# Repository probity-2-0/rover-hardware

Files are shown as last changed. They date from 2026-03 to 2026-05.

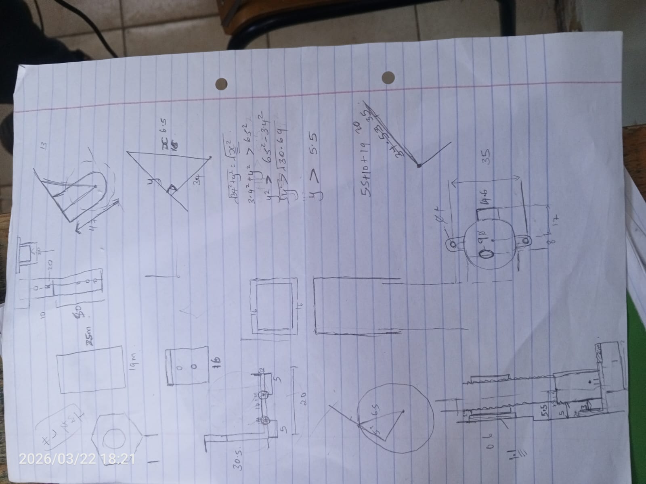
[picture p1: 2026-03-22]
images/SUSPENSION.jpeg

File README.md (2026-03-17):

# # Rover Hardware
Hardware design(Mechaical & Electrical design files) and documentation for the rover, including schematics, wiring diagrams, components, embedded system interfaces, CAD models(fusion 360).

This repository contains all mechanical and electrical designs for the Mars Rover project.

## Contents
- Mechanical design (CAD, chassis, structure)
- Electrical systems (schematics, wiring, PCB)
- Components and parts list (BOM)
- Hardware images and prototypes

## Structure
- mechanical/
- electrical/
- components/
- images/

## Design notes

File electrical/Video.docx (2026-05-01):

This documentation guide addresses the technical integration of a RunCam FPV Camera with a Network Card (WiFi Dongle) for digital FPV transmission and RunCam WifiLink, likely via the OpenIPC or RubyFPV ecosystem.

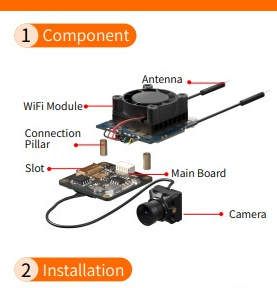
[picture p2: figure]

1. Video Signal Interface (Digital)

In this specific setup, the "Interface" is actually a two-part bridge:

- Camera to Main Board
- Main Board to WiFi Dongle

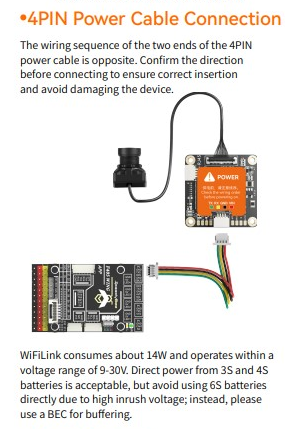
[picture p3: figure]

Operating Voltage & Current Draw

Digital transmission requires high current stability. Voltage ripple should be kept below 100mV.

- Operating Voltage: 9V – 30V (Optimized for 3S/4S LiPo).
- Typical Current (Idle): 450mA @ 12V.
- Typical Current (Streaming): 1.2A @ 12V.
- Max Peak Current: 2.5A @ 12V (During high-bitrate scene changes or extreme range transmission).

2. WiFi Channel & Frequency Configuration

The system uses the 5.8 GHz band. It is highly configurable via a text file on the SD card.

- Default Frequency: 5.8 GHz.
- Supported Power: Up to 29dBm (approx. 800mW) on FCC settings.
- Channel Selection: Recommended to use Channel 149 (5745 MHz) to 165 (5825 MHz) to stay clear of standard WiFi routers.
- Codec: H.265 is preferred for digital FPV as it offers better quality at lower bitrates, reducing latency.
- Ground Station: ground station WiFi dongle must be put into Monitor Mode.Need the gs.key file (automatically generated on the camera's SD card) to decrypt the video stream on your ground station device.

3. Antenna Placement (LoRa Interference Check)

Since the rover also carries a LoRa link:

- WiFi Antenna: 5.8 GHz (Circular Polarized or "Mushroom" antennas are best for multi-path rejection).
- LoRa Antenna: 433/868/915 MHz (Linear Monopole/Dipole).
- Interference Rule: WiFi 5.8 GHz is a harmonic of some lower frequencies. Keep the WiFi antenna at least 20cm away from the LoRa antenna. If you experience "telemetry lost" when the video starts, the WiFi dongle is likely "swamping" the LoRa receiver.

4.Specification

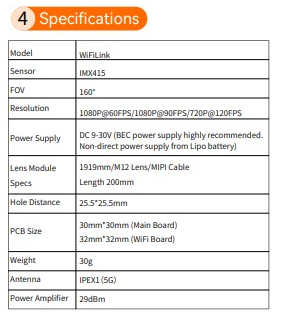
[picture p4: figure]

5. Mounting Strategy (Remote Cable-Mount)

The WiFiLink 2 is modular. You can "remote-mount" components to balance the rover or move the RF source.

- Camera Mount: The sensor (19x19mm) can be mounted up to 130mm away from the main board using the provided MIPI cable.
- Board Mount: The main PCB (32x 32mm) should be mounted on 25.5mm stacks.
- Thermal Note: The board must have its cooling fan active. If the green/blue lights flash alternately, the board has exceeded 90°C and will throttle or shut down.
- WiFi Dongle: Can be remote-mounted using a 4-wire shielded cable to place the antenna in the most optimal RF location.

6.Ground Station Configuration

To receive the signal on the ground station side, you need:

1. Hardware: A high-power WiFi dongle (typically RTL8812AU or MT7612U chipsets).
2. Software:
  - Android: FPVue or PixelPilot.
  - PC: Use the FPV4Win tool.

GS Key Management: Always keep a backup of the gs.key on a secondary device. If you lose this file from the SD card, you will lose the ability to decrypt the video stream on your Ground Station.

7.Communication Protocol

- Internal (Cam to Board): MIPI CSI-2 (4-Lane).
- External (Board to GS): UDP/RTSP over WiFi (Monitor Mode).
- Telemetry: MAVLink via UART (compatible with ArduPilot/PX4).
- Control: I2C is used internally for sensor configuration; it is not exposed for user control.

6. Testing Procedure (Bench Test Checklist)

1. Continuity Check: Verify no shorts between VCC and GND before applying power.
2. Voltage Check: Confirm the BEC/PDB outputs 12V stable under load.
3. LED Status: Red Solid (Power), Blue Flashing (System Boot), Green Solid (WiFi Link Active).
4. Ping Test: Connect GS to WiFi and ping the camera IP (Default: 192.168.1.10).
5. Latency Check: Measure glass-to-glass latency (Target < 80ms

8. Board Placement & Thermal Rules

- Thermal: The SoC generates significant heat. The board must be mounted with at least 5mm of clearance underneath for airflow.
- Proximity: Keep the WiFiLink board at least 50mm away from the GPS module and 150mm away from the LoRa receiver.
- Mounting: Use M2 nylon standoffs to prevent shorting against carbon fiber or metal rover frames.

PCB Trace Width Recommendations

For the JST_GH_1x04_P1.25mm connector, the power traces must be sized to handle peak current without significant voltage drop or heat buildup.

- VCC & GND Traces: Use a trace width of at least 1.0 mm (40 mils) for internal or external layers if using standard 1oz copper. This safely handles the 2.5A peak current while keeping temperature rise under 10°C.
- UART Data Traces (TX/RX): These carry minimal current and can be thin, typically 0.2 mm (8 mils), but keep them away from high-power traces to avoid EMI.
- Polygon Pours: Whenever possible, use a Ground Plane on the layer directly beneath the WiFiLink to provide a short return path for high-frequency noise.

79 Firmware & Code Notes

- OS: Linux-based OpenIPC.
- Library: Uses WFB-ng (WiFi Broadcast next generation) for the transmission layer.
- HAL: The hardware abstraction layer is proprietary to the SigmaStar SoC, but can be modified via /etc/config/ files via SSH.
- Root Access: ssh root@192.168.1.10 (Default password is often 12345 or runcam).

10. Recommended Schematic Circuit

When integrating this into your rover's power distribution board (PDB):

- Decoupling: Place a 470µF 35V Low-ESR Capacitor across the DC input to filter motor noise.
- Protection: Add a TVS Diode (e.g., SMBJ24A) to protect against voltage spikes from the rover's motors.
- Symbol Name: JST_GH_1x04_P1.25mm

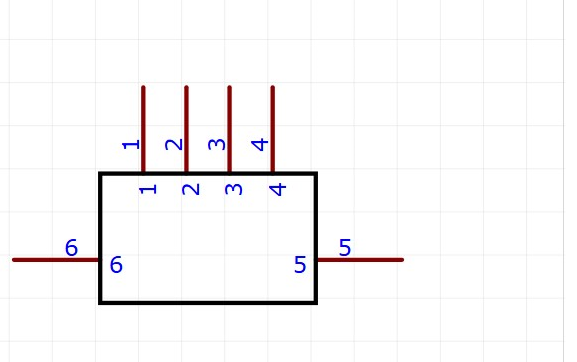
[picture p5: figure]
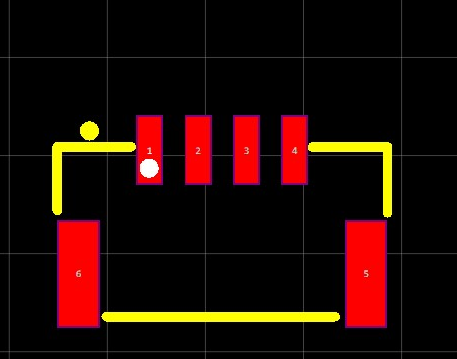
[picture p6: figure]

General Description and Purpose

The JST_GH_1x04 is a 4-pin, 1.25mm pitch wire-to-board connector symbol used to define the primary electrical interface for the WiFiLink system. In professional electronics design, this symbol serves three critical purposes for your rover build:

- Power Delivery Integration: It provides the schematic connection point for the 9V–30V DC input, ensuring the high-current requirements (up to 2.5A peak) are routed through traces capable of handling the load.
- Telemetry Communication Bridge: The symbol maps the UART TX and RX lines, allowing you to establish a MAVLink communication protocol between the WiFiLink board and the rover's flight controller or main processor

Pin | Function | Description
1 | VCC | Main Power Input
2 | GND | Common System Ground
3 | TX | Data output to Flight Controller (Telemetry)
4 | RX | Data input from Flight Controller (Control)
5 & 6 | Shielding | which should be soldered to a grounded plane for physical stability and additional noise shielding

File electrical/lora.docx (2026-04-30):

E220-400T22D adopts a new generation of LoRa spread spectrum technology and a wireless serial port module (UART) designed based on the LLCC68 chip scheme. It has a variety of transmission methods, works in the (410.125～493.125MHz) frequency band (default 433.125MHz), TTL level output, compatible with 3.3V and 5V IO port voltage.

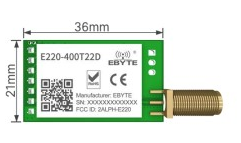
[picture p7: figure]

Pinout Description

The module generally includes the following pins, starting from the antenna end:

Pin Name | Description
M0 | Mode selection pin 0 (Used with M1 for sleep/wake/power-saving modes)
M1 | Mode selection pin 1 (Used with M0)
RXD | TTL UART Serial Input (Connects to MCU TX)
TXD | TTL UART Serial Output (Connects to MCU RX)
AUX | Auxiliary indication (Indicates module state, wakes up external MCU)
VCC | Power Supply (Typically 3.3V - 5.2V)
GND | Ground (0V)

Key Features

- Operating Frequency: 433-532MHz band
- Interface: UART (Serial)
- Distance: Long-range (LoRa technology)
- Antenna: SMA or solder pin for external antenna (essential for range)
- Operating Temperature: -40~+85 ℃

Performance:

- Output Power: +22dBm
- Maximum Receiving Sensitivity: -135dBm (BW=125, SF=12)
- Open space visible distance up to 8km (for reference only, actual distance may vary)

EASYEDA SCHEMATIC/DIAGRAM

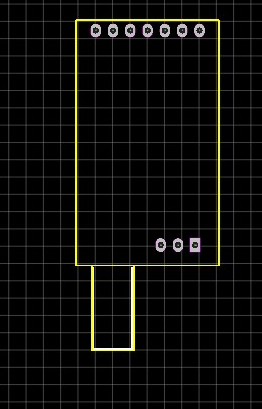
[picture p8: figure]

FootPrint

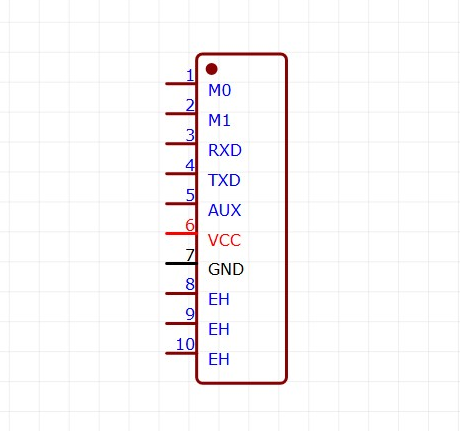
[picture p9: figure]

Hardware Design Layout Suggestions

The E220-400T22D module operates in the 433-532M frequency band and uses an external antenna. The antenna's VSWR and efficiency depend on the module's placement. Minimize factors affecting wireless transmit and receive signals. Pay attention to the following points:

Avoid using metal for the product casing surrounding the E220-400T22D. If using a partial metal casing, keep the module's antenna section as far away from the metal as possible. Internal metal connections or screws should also be kept away from the module's antenna section.

The module's antenna section should be placed near the edge of the carrier board PCB or directly exposed, and should not be placed in the middle of the board.

It is recommended to use insulating material for isolation at the module mounting position on the baseboard, such as a complete silk screen (TopOverLay) at this location

Recommended Circuit

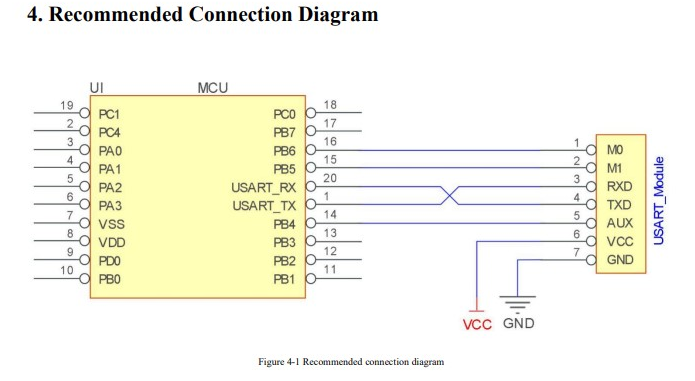
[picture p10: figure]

Precautions

- Power Check: Ensure the module is receiving stable power within the specified voltage range (3.3V-5.5V).
- Antenna Connection: Verify that the antenna is securely connected before powering on the module. An unconnected antenna can lead to damage.
- UART Connection: Double-check your RXD and TXD connections to your microcontroller or computer. Ensure baud rates match.
- AT Command Syntax: Confirm that the AT commands sent are correctly formatted and terminated. Refer to the technical manual for exact syntax.
- Frequency Band: Ensure both transmitting and receiving modules are configured to the same frequency band.
- Communication Range: Consider environmental factors (obstacles, interference) that might affect the actual communication range. The stated 8km range is for open, unobstructed environments.
- Module Operating Mode: Verify that the M0 and M1 pins are configured correctly for the desired operating mode (e.g., transparent, fixed-point).

TX power setting and link budget calculation

TX Power Settings

The maximum transmit power for these "22D" series modules is typically +22 dBm (160mW).

- Adjustment Range: Usually configurable from 0 dBm to +22 dBm in steps.
- Power Consumption: Higher TX power significantly increases current draw during transmission. For example, at +22 dBm, the module may draw over 100mA, whereas lower settings like +10 dBm draw much less.
- Regulatory Limits: In many regions, the 433 MHz ISM band has strict effective radiated power (ERP) limits (often 10mW or 14 dBm) and duty cycle restrictions. Ensure your settings comply with local laws

Link Budget Calculation

The link budget is the sum of all gains and losses in your communication system. It determines the maximum path loss your signal can survive before it becomes unreadable

Received Power(dBm)=PTX+GTX-LTX-FSPL+GRX-LRX

PTX(TX Power): Your setting (e.g., +22 dBm).

GTX/GRX(Antenna Gain): Typical rubber ducky antennas are ~2 dBi.

LTX/LRX(Cable/Connector Loss): Usually ~0.5–1 dB for direct SMA connections.

FSPL (Free Space Path Loss): The loss over distance d (km) at frequency (MHz):

FSPL=20log10(d) + 20log10(f)+32.45

Fade Margin: Always subtract a safety margin (e.g., 10–15 dB) for obstacles and weather to ensure reliability.

Range Test Protocol

Step 1: Static Bench Test (0.5km)

- Goal: Verify the ACK Loop logic works.
- Action: Send 100 commands. If the Ground Station logs 100 ACKs, the firmware is stable.

Step 2: Line-of-Sight (LoS) Test (5km - 8km)

- Action: Have the Rover assignee move to a clear hilltop.
- Data: Record the RSSI (Signal Strength) and SNR (Signal Quality) reported by the module.
- Orientation: Test if holding the Ground Station antenna Vertical vs. Horizontal changes the signal.

Step 3: Failure Boundary Test

- Action: Move until the "Heartbeat" starts dropping.
- Goal: Confirm the Rover's Fail-Safe triggers (Motors stop) when the signal is lost.

Firmware and Code Libraries

The E220-400T22D is primarily a UART-based module, meaning most developers interact with it via serial strings rather than low-level register manipulation

1. Core Architecture

- Driver Type: Because the module includes an onboard MCU to handle the LoRa stack, you generally use HAL drivers for UART on your host controller (e.g., STM32 HAL, Arduino Serial) rather than SPI HAL drivers for the LoRa chip itself.

2. Register Maps & Configuration

The module does not expose the raw SX1262 register map over UART. Instead, it uses a Virtual Register Map accessed via AT commands.

- Configuration Storage: Settings changed via AT commands are typically stored in the LLCC68's internal Flash/EEPROM, persisting through power cycles.
- Register Access: This specific EByte module usually uses Hexadecimal Configuration Commands

3. Recommended Libraries

For most microcontrollers, you do not need a specific "LR32" library. You can use standard serial libraries:

- Arduino: SoftwareSerial (https://docs.arduino.cc/learn/built-in-libraries/software-serial/) or hardware Serial for basic data. For structured control, the EByte E32 Library (https://github.com/xreef/LoRa_E32_Series_Library) is often partially compatible due to similar pinouts and UART logic.
- STM32: Use the STM32 HAL UART (https://www.st.com/resource/en/user_manual/um2642-description-of-stm32wl-hal-and-lowlayer-drivers-stmicroelectronics.pdf) with DMA for high-speed telemetry.

4. Code Implementation Notes

- Interrupt-Driven RX: Always use an interrupt or DMA on your host MCU to read from the module. LoRa packets arrive asynchronously; if your code is "blocked" in a delay, you will miss telemetry.
- The AUX Pin: This is your hardware "Interrupt" pin.
  - High: Module is idle/ready.
  - Low: Module is busy (transmitting or receiving).
  - Code Tip: Use a falling-edge interrupt on the host MCU's AUX-connected pin to trigger a serial read.
- Data Buffering: The module typically has a 230-byte buffer. Sending more than this in one burst without checking the AUX pin status may result in data loss.

PCB Antenna Design

433 MHz Band (Global)

The 433 MHz band is available in many regions but with varying power limits and restrictions.

Key specifications:

- Center frequency: 433.92 MHz
- Bandwidth: Typically 125 kHz
- Max TX power: +22 dBm (160 mW) in EU, varies elsewhere
- Longer range potential due to lower frequency

Frequency | Full Wavelength (λ) | Quarter-Wave (λ/4) | Half-Wave (λ/2)
433 MHz | 692 mm | 173 mm | 346 mm

Use external ¼ Wave Whip Antenna

Connect to SMA Female Edge-Mount Connector

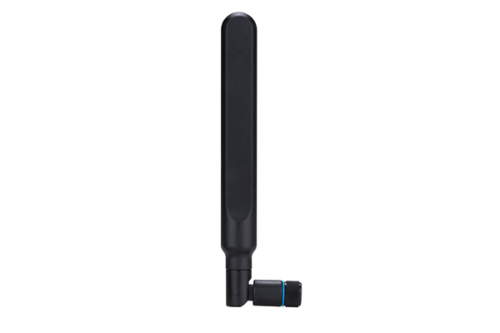
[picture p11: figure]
32256 4G/3G Cellular Whip Antenna with SMA Connector

Minimum Ground Plane Dimensions

Frequency | Minimum Size | Recommended Size | Notes
433 MHz | 80 × 100 mm | 100 × 150 mm | Larger is better

Ground Plane Design Rules for LoRa

Rule 1: No copper under the antenna

The entire antenna keep-out zone must be free of copper on ALL layers. For a 868 MHz meandered monopole, this means a 45mm × 15mm (minimum) region with no ground, power, or signal traces.

Rule 2: Ground plane edge position

The edge of the ground plane nearest the antenna significantly affects performance. Keep this edge straight and perpendicular to the antenna feed direction.

Rule 3: Via stitching requirements

At sub-GHz frequencies, via spacing can be more relaxed than at 2.4 GHz, but still important:

Frequency | Maximum Via Spacing
433 MHz | 15–20 mm

Rule 4: Ground continuity

For multi-layer boards, ensure ground continuity between layers in the antenna region. Avoid routing signals through the antenna ground area on internal layers.

Feed Line Design for LoRa Frequencies

The transmission line from your LoRa module to the antenna must maintain 50Ω characteristic impedance.

Microstrip Dimensions for Sub-GHz

At lower frequencies, trace widths for 50Ω are wider than at 2.4 GHz:

PCB Thickness (https://pcbsync.com/pcb-thickness/) | Trace Width for 50Ω | Notes
0.8 mm | 1.5 mm | 4-layer boards
1.0 mm | 1.9 mm | Common 4-layer
1.6 mm | 3.0 mm | Standard 2-layer

Coplanar Waveguide (CPW) for LoRa

CPW provides better ground return and is often preferred:

PCB Thickness | Trace Width | Gap to Ground | Total Width
1.6 mm | 2.0 mm | 0.4 mm | 2.8 mm
1.6 mm | 1.5 mm | 0.3 mm | 2.1 mm

Feed Line Best Practices

- Keep feed lines short (loss increases with length)
- Avoid sharp bends; use 45° miters if necessary
- Maintain consistent width throughout
- Don’t route over split planes or near board edges

Impedance Matching for LoRa PCB Antennas

LoRa antennas often need matching networks to optimize performance across the operating band.

Pi Matching Network

The standard matching topology:

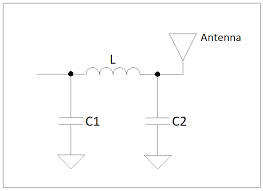
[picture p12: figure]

Only include a "Zero-Ohm Resistor" (jumper) or a single series capacitor (approx. 100pF) in the path to the antenna to protect against DC shorts

Packet Structure

System Architecture: The "Master-Slave" Flow

The Ground Station acts as the Master node. It initiates commands and expects confirmation, while the Rover acts as the Slave node, providing telemetry (status updates) and executing instructions.

The Logic Flow:

1. Idle State: Ground Station monitors the AUX pin. If HIGH, the LoRa module is ready.
2. Command Phase: Ground Station packages a "Fixed Schema" binary packet and sends it via UART.
3. Validation Phase: The Rover receives the packet, verifies the CRC-16 checksum, and checks if the Target ID matches its own.
4. Acknowledgment (ACK): For critical commands, the Rover sends a tiny confirmation packet back. The Ground Station waits for this; if not received within a timeout window (e.g., 500ms), it automatically retries.

2. The "Fixed Schema" Packet Logic

Instead of sending text (which is slow and bulky), we use a Binary Struct. This ensures the absolute minimum "Time-on-Air," which is critical for maintaining an 8km link without interference.

- Standardized Length: Every packet is a fixed size (e.g., 8 or 10 bytes). This prevents "buffer overflow" in the E220's 230-byte internal memory.
- Byte Alignment: Data is packed tightly using Little-Endian format to match the STM32's native processing, ensuring no data is lost during the conversion from ground to rover.

3. Data Integrity & Safety Standards

To ensure the rover doesn't behave unpredictably at long distances, we implement three specific logic layers:

- Scaling (Efficiency): We eliminate 4-byte "Floating Point" numbers. Instead, we multiply values (like Battery Voltage) by 100 to send them as 2-byte integers, cutting payload size in half.
- Idempotency (Duplicate Prevention): Every command has a unique Msg ID. If a retry causes the Rover to receive the same "Turn Left" command twice, the Rover recognizes the duplicate ID and ignores the second instruction.
- The Heartbeat (Telemetry): The Rover sends a status update every 1–2 seconds. If the Ground Station misses several heartbeats, it triggers a "Signal Lost" alarm for the operator.

4. Hardware Management (The AUX Pin)

The most important piece of logic for the E220 module is the Hardware Handshake.

- Logic: The code must "Listen" to the AUX pin before every transmission.
- Purpose: If AUX is LOW, the module is busy transmitting or receiving. Sending UART data during this time will cause data corruption or buffer loss.

Byte # | Name | Value / Example | Why it's here
0 | Target ID | 0x01 (Rover) | Tells the Rover: "This is for you".
1 | Sender ID | 0xFE (Ground) | Tells the Rover: "This is from HQ".
2 | Command | 0xA1 (Drive) | The “What to do “ Code
3 | Data A | 0xFF(Speed) | Primary variable(e.g Throttle)
4 | Data B | 0x7F(Steer) | Secondary variable( e.g Steering angle)
5 | Msg ID | 0-255 | An incrementing number for idepomtency
6-7 | CRC-16 | 0xABCD | The math check to ensure the data is “clean”

NOTE:

We shifted from SPI to UART because our hardware (E220-400T22D) is a System-on-a-Module. Using UART allows us to offload the complex LoRa timing to the module's internal processor, reducing the STM32's CPU load and simplifying our firmware to a basic 'Serial Bridge'. This ensures maximum stability for the 8km link without the risk of SPI timing failures.

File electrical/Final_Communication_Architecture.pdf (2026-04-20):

## Probity002 Final Communication Architecture Design

Wogambula
Grace
Brumuel

20 April 2026

## 1 Project Overview

This document presents the final design of the wireless communication and real-time control subsystem for the Mars Rover Prototype. The system enables reliable bidirectional data transfer between a ground control station (PC) and the rover, delivering live 1080P video telemetry and precise motor/sensor control over a Wi-Fi link. Designed specifically for Earth-based testing and simulation of Mars rover operations, the architecture ensures low-latency command execution and high-fidelity visual feedback, critical for remote exploration missions.

## 2 System Architecture

The communication and control architecture is illustrated in the block diagram below and comprises the following core components:

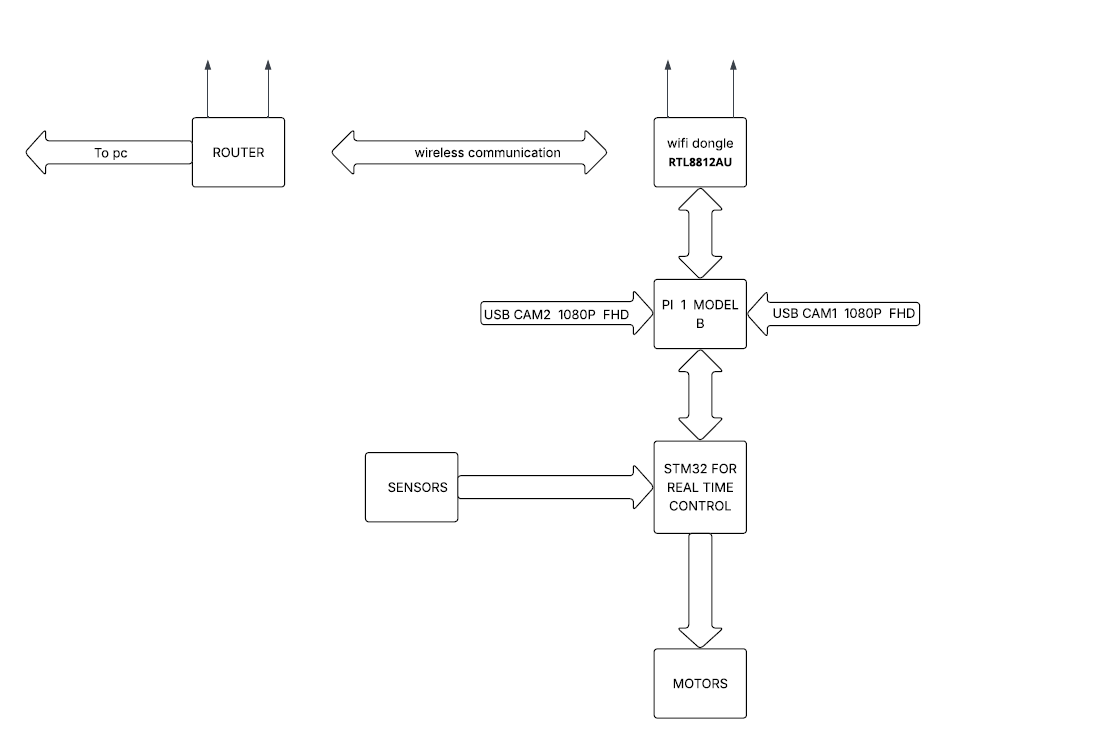
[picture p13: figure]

Figure 1: Signal Flow Diagram

- Ground Control Station: Standard PC connected to a router for command transmission and video reception.
- Wireless Communication Link: RTL8812AU Wi-Fi dongle mounted on the rover provides robust bidirectional wireless connectivity.
- Onboard Processing Unit: Raspberry Pi 1 Model B serves as the central communication and vision processor.
- Real-Time Control Unit: STM32 microcontroller dedicated to low-level sensor acquisition and motor actuation.
- Vision System: Two USB 1080P Full-HD cameras (CAM1 and CAM2) for stereo-like environmental monitoring.
- Actuation and Sensing: DC motors for mobility and various sensors (IMU, distance, temperature, etc.) interfaced directly to the STM32.

## 3 System Functionality

The system operates as a closed-loop wireless telemetry and control platform as follows:

1. Command Transmission: The ground control PC sends motor commands, camera settings, and system queries through the router.
2. Wireless Reception: The RTL8812AU Wi-Fi dongle receives the data packets and forwards them to the Raspberry Pi 1 Model B via USB.

3. Data Processing and Relay: The Raspberry Pi processes incoming commands and transmits them to the STM32 microcontroller using a high-speed UART/SPI interface. Simultaneously, the Pi streams compressed 1080P video feeds from both USB cameras back to the ground station.
4. Real-Time Control: The STM32 microcontroller reads real-time sensor data, executes precise PID-based motor control algorithms, and returns telemetry packets (sensor values, motor status, and health metrics) to the Raspberry Pi.
5. Bidirectional Telemetry: All data is exchanged in real time, allowing the operator to monitor the rover’s surroundings visually while adjusting navigation and operations instantaneously.

The clear separation of real-time deterministic tasks (STM32) from communication and video processing (Raspberry Pi) guarantees system stability even under variable wireless conditions or high video bandwidth loads—essential for Mars rover prototype validation.

## 4 Total Project Cost

The complete communication and control subsystem, including all components shown in the block diagram (Raspberry Pi 1 Model B, STM32 microcontroller, RTL8812AU Wi-Fi dongle, two 1080P USB cameras, sensors, motors, wiring, power distribution, and protective enclosure), can be procured and assembled locally for a total cost of KES 6,000. This budget reflects current market prices in Kenya and ensures the prototype remains highly affordable while meeting all performance requirements.

## 5 Key Benefits and Mission Relevance

- Robust wireless range and data integrity via RTL8812AU module
- Dual 1080P live video telemetry for enhanced situational awareness
- Deterministic real-time control of locomotion and sensors
- Low-cost implementation suitable for academic and research prototypes
- Scalable architecture for future addition of autonomous navigation modules

This final design fully satisfies the communication and control requirements of the Mars Rover Prototype project. Assembly and integration can commence immediately upon approval.

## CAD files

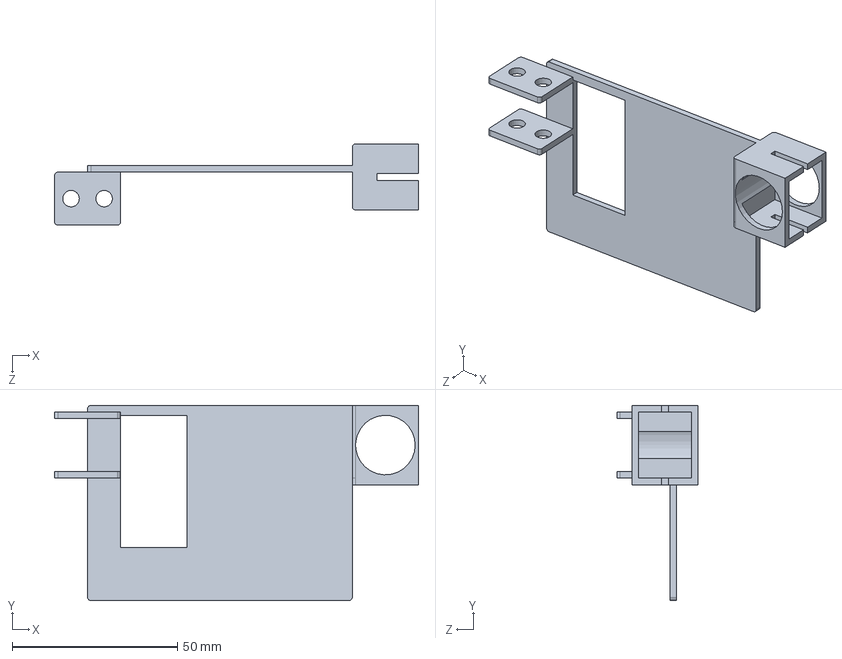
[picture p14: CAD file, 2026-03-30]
jude-mechanical designs/some good parts/servo rotation strength fixture-rare.SLDPRT
110.0 x 59.0 x 24.5 mm

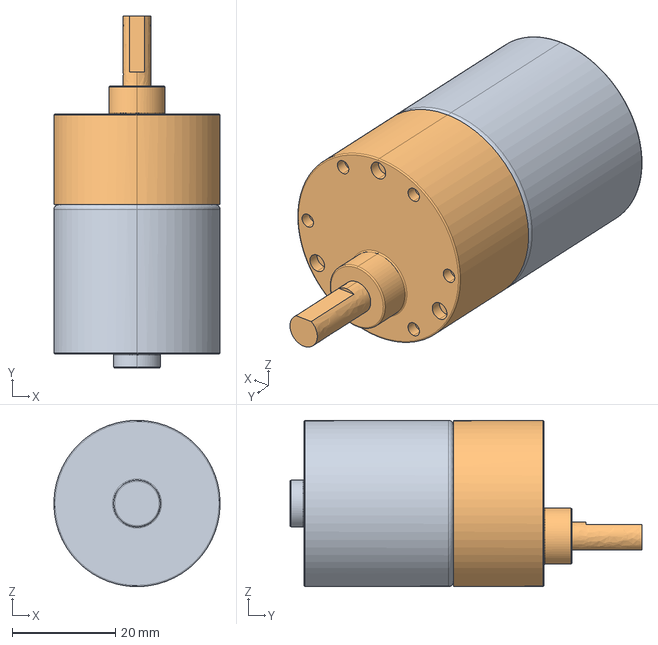
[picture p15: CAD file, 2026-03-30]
mechanical/Suspension/Suspensionsystema1/unusedparts/Wheelforwardmotion.step
32.2 x 68.2 x 32.2 mm

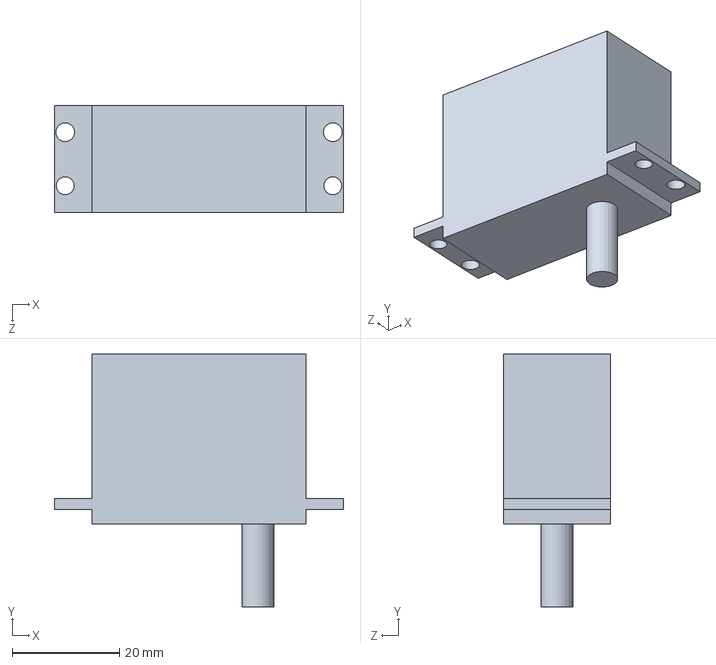
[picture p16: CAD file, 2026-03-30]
jude-mechanical designs/my_mg996r.SLDPRT
54.0 x 47.2 x 20.0 mm

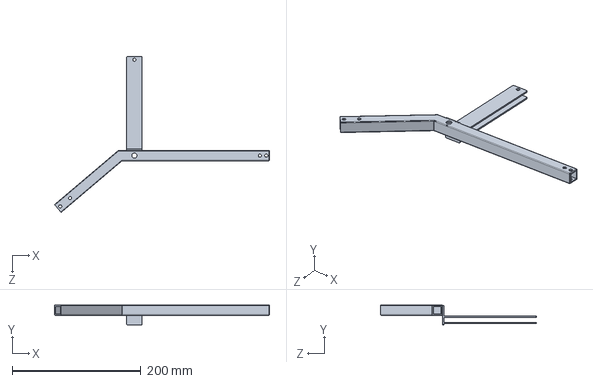
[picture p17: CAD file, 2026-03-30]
jude-mechanical designs/some good parts/rare middle part mirror.SLDPRT
334.1 x 31.0 x 242.3 mm

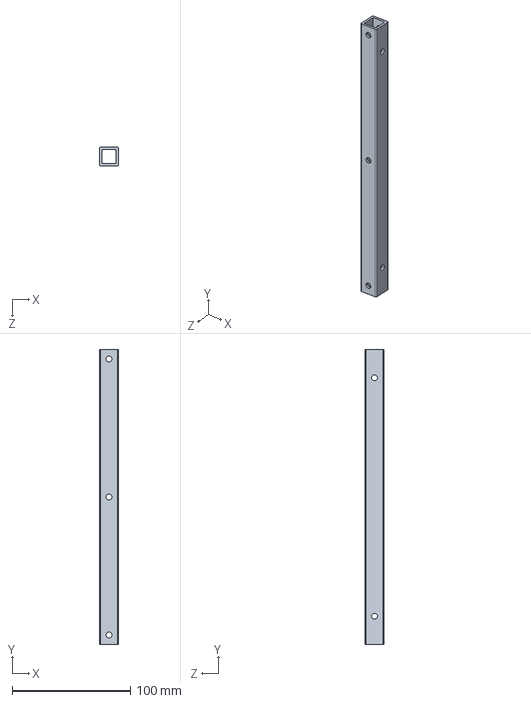
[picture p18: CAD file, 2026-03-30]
jude-mechanical designs/body z member.SLDPRT
16.0 x 250.0 x 16.0 mm

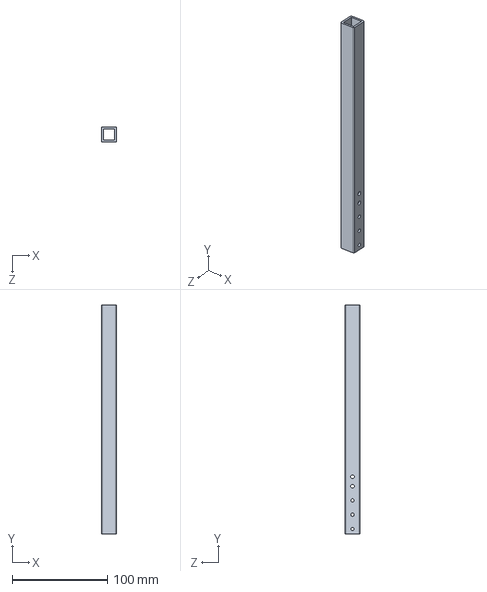
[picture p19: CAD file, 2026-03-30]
jude-mechanical designs/16mm inner tube.SLDPRT
16.0 x 240.0 x 16.0 mm

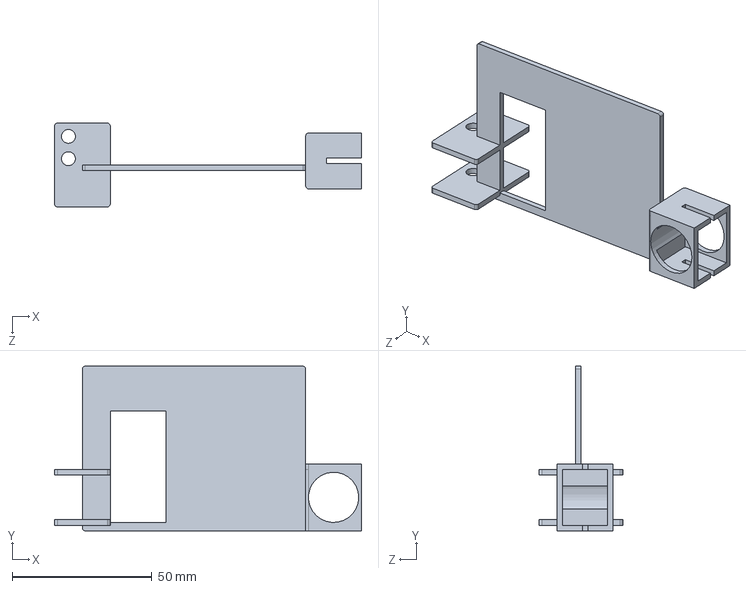
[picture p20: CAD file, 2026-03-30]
jude-mechanical designs/some good parts/servo rotation strength fixture mirror.SLDPRT
110.0 x 59.0 x 30.0 mm

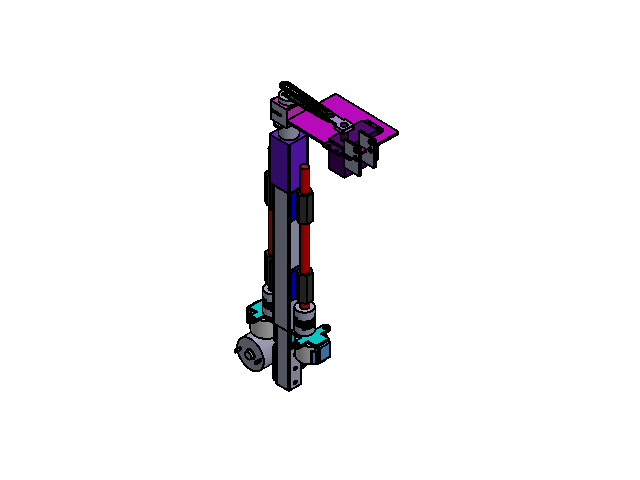
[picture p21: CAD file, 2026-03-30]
jude-mechanical designs/some good parts/right wheel suspension right.SLDASM
16mm inner tube
motor-bracket combined
suspension stepper bracket x 2
byj28--48 x 2
5to8 flexible coupler x 2
20mmsteel tube
nut support x 4
nut x 4
suspension pin x 2
servo whee suspension connector cup
servo rotation strength fixture mirror
my_mg996r
slider pin
suspension rotary pin

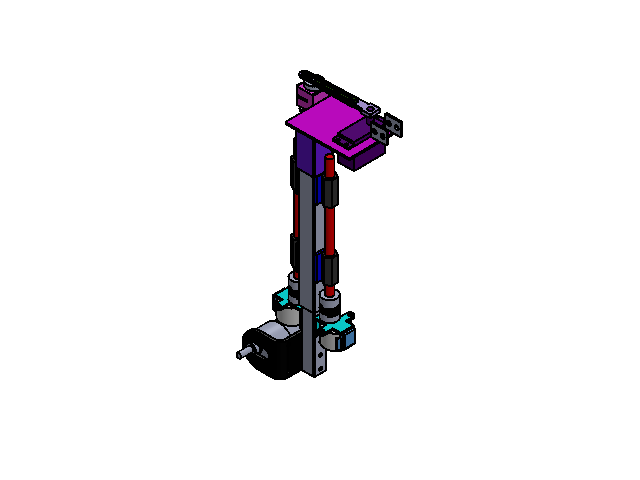
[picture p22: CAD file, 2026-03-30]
jude-mechanical designs/right wheel suspension rare.SLDASM
16mm inner tube
suspension stepper bracket x 2
byj28--48 x 2
5to8 flexible coupler x 2
20mmsteel tube
nut support x 4
nut x 4
suspension pin x 2
servo whee suspension connector cup
motor-bracket combined
servo rotation strength fixture-rare mirror
my_mg996r
suspension rotary pin
slider pin

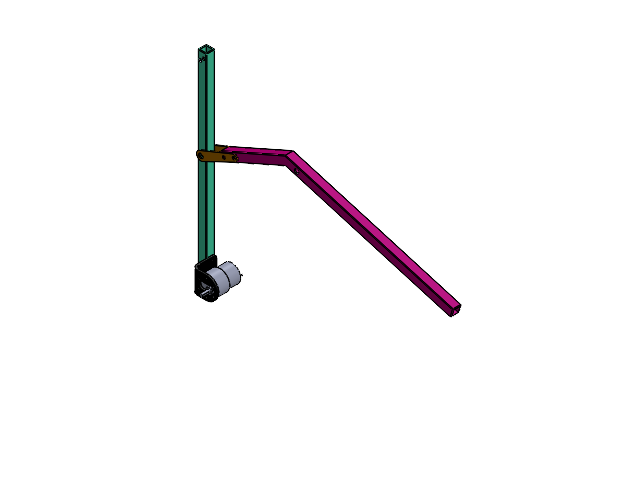
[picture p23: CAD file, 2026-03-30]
jude-mechanical designs/rear and middle wheel suspension.SLDASM
middle16mm
motor-bracket combined
rare middle part
connection bracket x 2

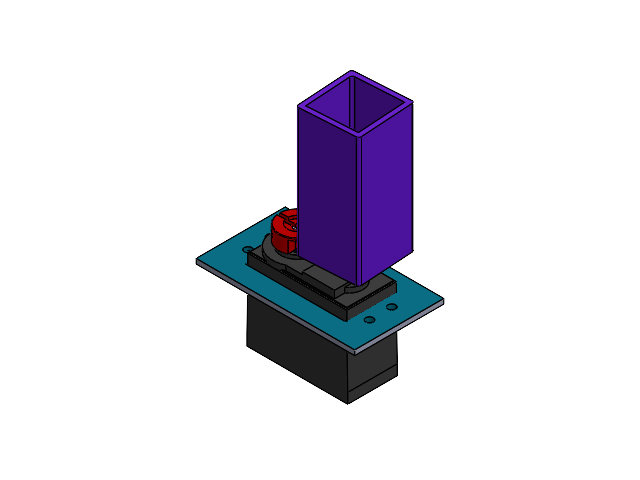
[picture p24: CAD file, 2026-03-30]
jude-mechanical designs/servomotor sub assembly.SLDASM
MG996R_servo
servo attachment
SERVO ARM HORN 25T ALUMINIUM
servo whee suspension connector cup

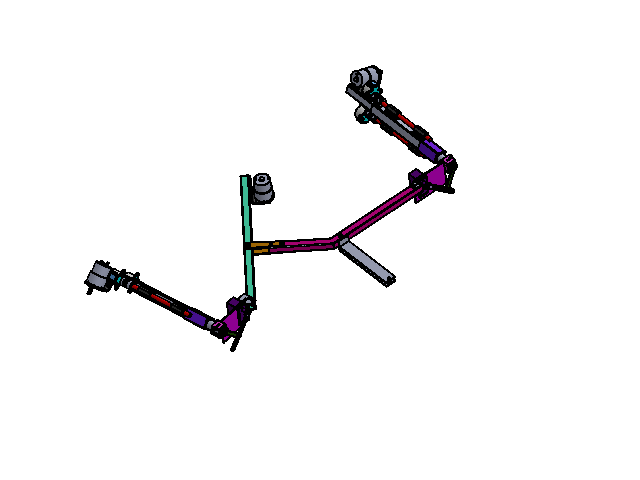
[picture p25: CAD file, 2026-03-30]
jude-mechanical designs/wheel suspension.SLDASM
16mm inner tube x 2
suspension stepper bracket x 4
20mmsteel tube x 2
nut support x 8
nut x 8
byj28--48 x 4
5to8 flexible coupler x 4
suspension pin x 4
servo whee suspension connector cup x 2
servo rotation strength fixture
suspension rotary pin x 2
slider pin x 2
my_mg996r x 2
motor-bracket combined x 3
middle16mm
rare middle part
connection bracket x 2
servo rotation strength fixture-rare

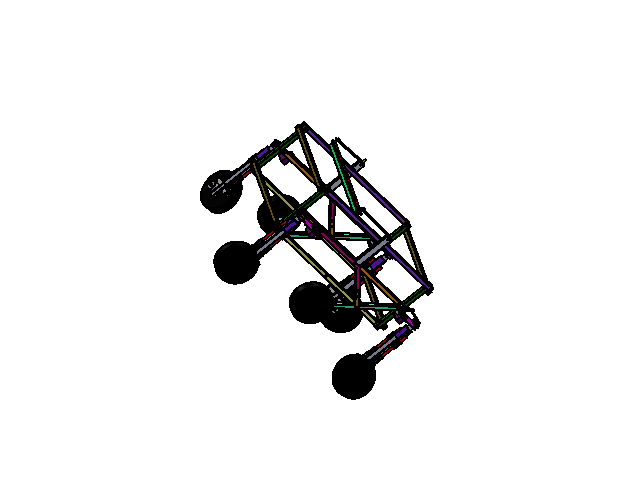
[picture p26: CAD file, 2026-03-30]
jude-mechanical designs/complete.SLDASM
16mm inner tube x 4
suspension stepper bracket x 8
20mmsteel tube x 4
nut support x 16
nut x 16
byj28--48 x 8
5to8 flexible coupler x 8
suspension pin x 8
servo whee suspension connector cup x 4
servo rotation strength fixture
suspension rotary pin x 4
slider pin x 4
my_mg996r x 4
motor-bracket combined x 6
middle16mm x 2
rare middle part
connection bracket x 4
servo rotation strength fixture-rare
body frame
servo rotation strength fixture-rare mirror
rare middle part mirror
servo rotation strength fixture mirror
tire mock up x 6
boggie
bogie pin x 2
connector pin x 2

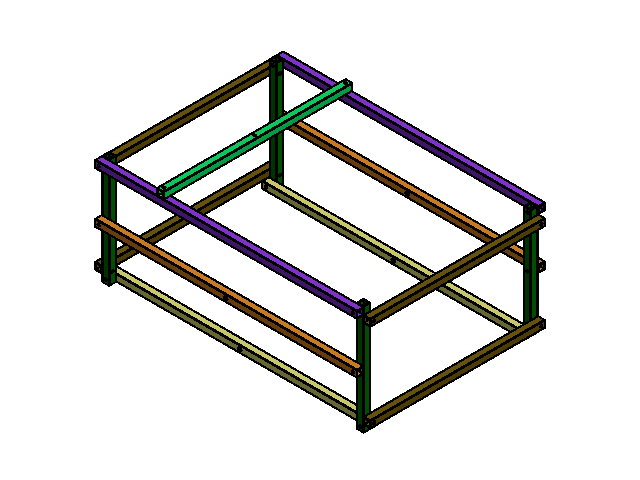
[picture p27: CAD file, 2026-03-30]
jude-mechanical designs/full body.SLDASM
body z member x 4
body width member x 4
body length member x 2
top cross member
button frame x 2
middle attachment frame x 2

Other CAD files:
jude-mechanical designs/rare wheel suspension.SLDASM
jude-mechanical designs/right full assembly.SLDASM
jude-mechanical designs/assembled servo system.SLDASM
jude-mechanical designs/some good parts/servo rotation strength fixture-rare mirror.SLDPRT
Placeholderjointouterring.ipt
Placeholderjointouterring_MIR.ipt
RISE&Fallmotor.ipt
RISE&Fallmotor_MIR.ipt
jude-mechanical designs/20mmsteel tube.SLDPRT
jude-mechanical designs/5to8 flexible coupler.SLDPRT
jude-mechanical designs/JGB37-520 12 v metal geared motor bracket.SLDPRT
jude-mechanical designs/JGB37-520-12v-319RPM.SLDPRT
jude-mechanical designs/M2 CAP HEAD SOCKET SCREW.SLDPRT
jude-mechanical designs/SERVO ARM HORN 25T ALUMINIUM.SLDPRT
jude-mechanical designs/body frame.SLDPRT
jude-mechanical designs/body length member.SLDPRT
jude-mechanical designs/body width member.SLDPRT
jude-mechanical designs/boggie.SLDPRT
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

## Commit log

2026-03-17 Create README.md
    Created the mechanical folder; Mechanical structure (chassis, wheels, suspension)
2026-03-17 Created electrical folder
    Electrical and Power systems systems (wiring, circuits, PCBs), Control Architecture
2026-03-17 Create Images folder
    Visual Documentation of mechanical and electrical wiring diagrams
2026-03-17 Create images folder
    Visual documentation using real life photos(expect prototypes, assembled rover etc.)
2026-03-30 this is our first cad designs to write our proposals
    [16mm inner tube.SLDPRT, 20mmsteel tube.SLDPRT, 5to8 flexible coupler.SLDPRT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]
2026-04-23 Add files via upload
    an updated version of the rocker bogie suspension with a cylindrical attachment to connect the suspension to the chassis. The length of the spoke has also been shortened to lower the minimum height of the rocker and also for all wheels to be in contact with the ground
    [Placeholderjointouterring.ipt, Placeholderjointouterring_MIR.ipt, RISE&Fallmotor.ipt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]
2026-04-30 Lora Communcation Module
    ## PR Title:
    `docs: Technical Specification for E220-400T22D LoRa System Architecture`
    ## PR Description:
    ### 📄 Overview
    This PR uploads the comprehensive technical documentation for the **E220-400T22D LoRa** communication system[cite: 1]. It establishes a standardized **System-on-a-Module (SoM)** architecture for both the Ground Station and Rover to ensure stable 8km data links.
    ### 🛠 Key Specifications
    * **Hardware Interface**: Utilizes **UART (TTL)** communication instead of raw SPI, offloading LoRa stack management to the internal **LLCC68** chip.
    * **Packet Logic**: Implements a **Fixed Schema Binary Struct** (8-byte payload) to minimize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
2026-05-01 docs: RunCam WiFiLink integration
    docs: add RunCam WiFiLink technical specifications
    - Uploaded pinout diagrams and function tables
    - Documented power budget and 9-30V DC requirements
    - Added WiFi channel configurations and LoRa interference rules
    - Included KiCad symbol mapping for JST_GH_1x04 connector
2026-05-05 Create guide.txt
    all the guidelines for documentation and support material will be here
